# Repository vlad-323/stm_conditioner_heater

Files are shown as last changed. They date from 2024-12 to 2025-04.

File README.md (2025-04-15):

# stm_conditioner_heater
 Прилад дозволяє керувати компресором, обігрівом компресора та обігрівом піддона.
 # Схема електрична принципова
project
 # Зовнішній вигляд приладу

 # Логіка роботи
 1. Ініціалізація усіх входів та виходів
 2. Якщо вхід компресора вимкнений -> компресор і ТЕН компресора вимкнені
 3. work in progress...

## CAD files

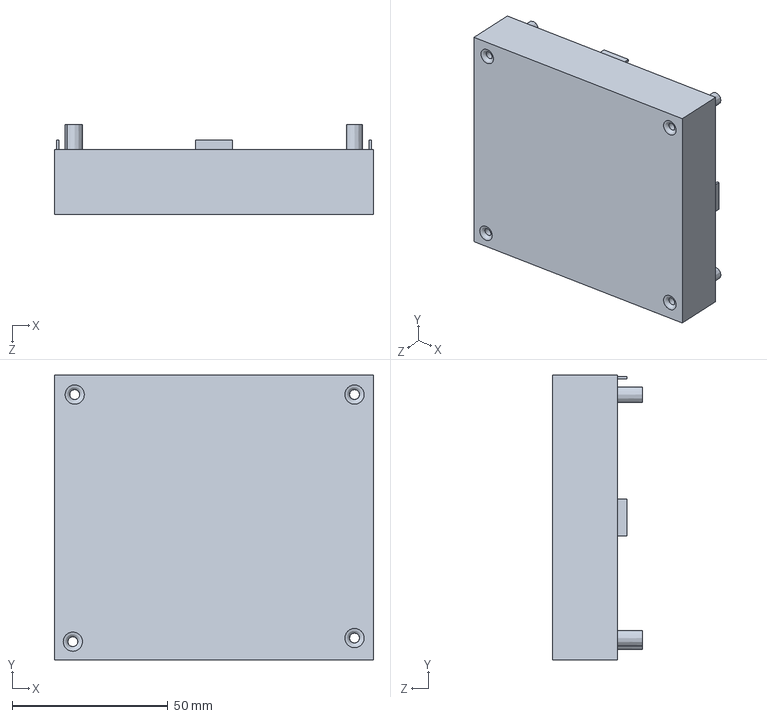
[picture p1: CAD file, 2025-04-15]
case/cond_control_TOP.SLDPRT
102.5 x 91.5 x 29.0 mm

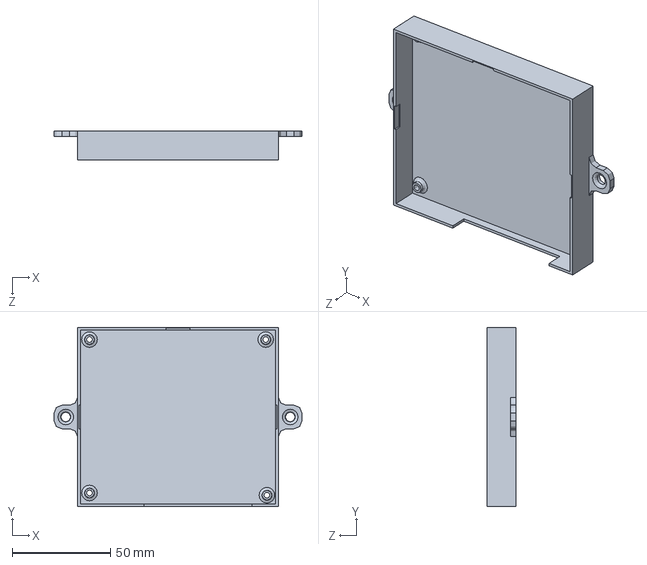
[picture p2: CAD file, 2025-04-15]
case/cond_control.SLDPRT
126.5 x 91.5 x 15.0 mm

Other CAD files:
case/cond_control.STL
case/cond_control_TOP.STL

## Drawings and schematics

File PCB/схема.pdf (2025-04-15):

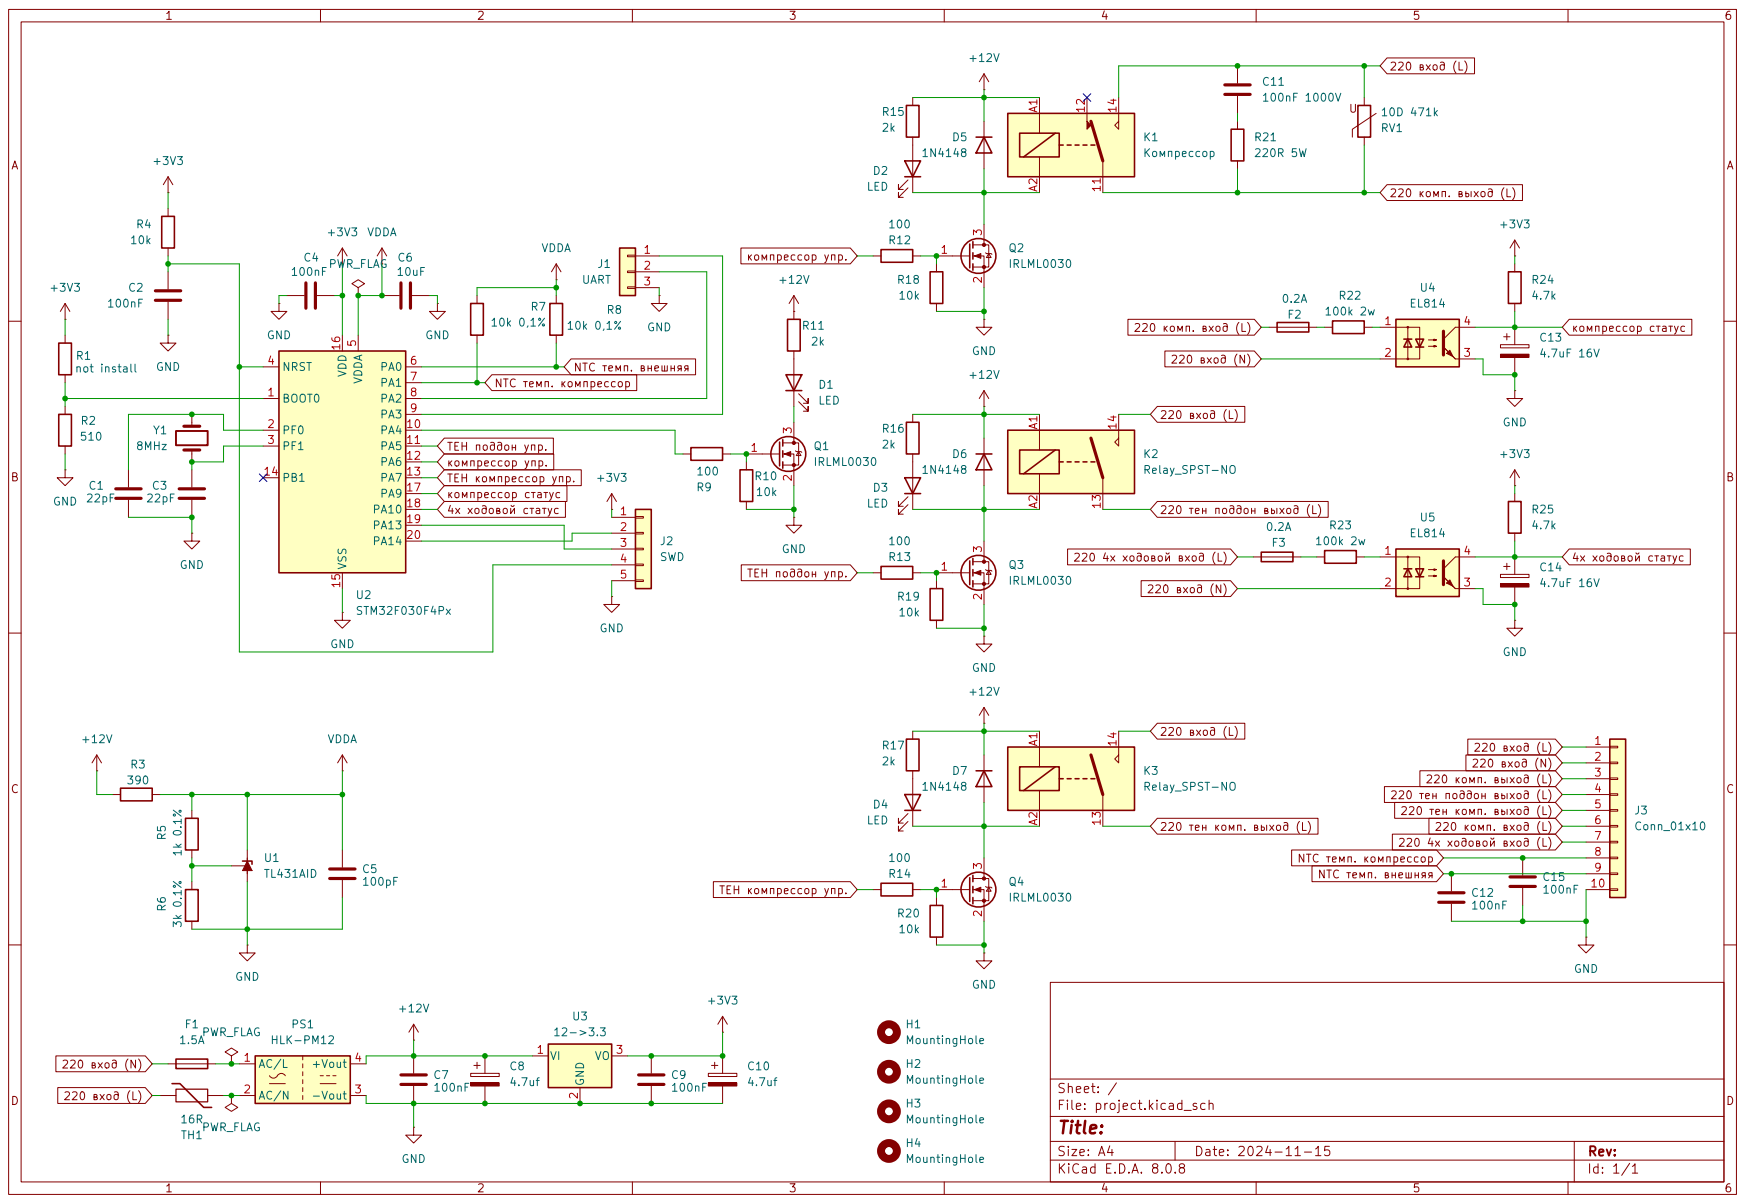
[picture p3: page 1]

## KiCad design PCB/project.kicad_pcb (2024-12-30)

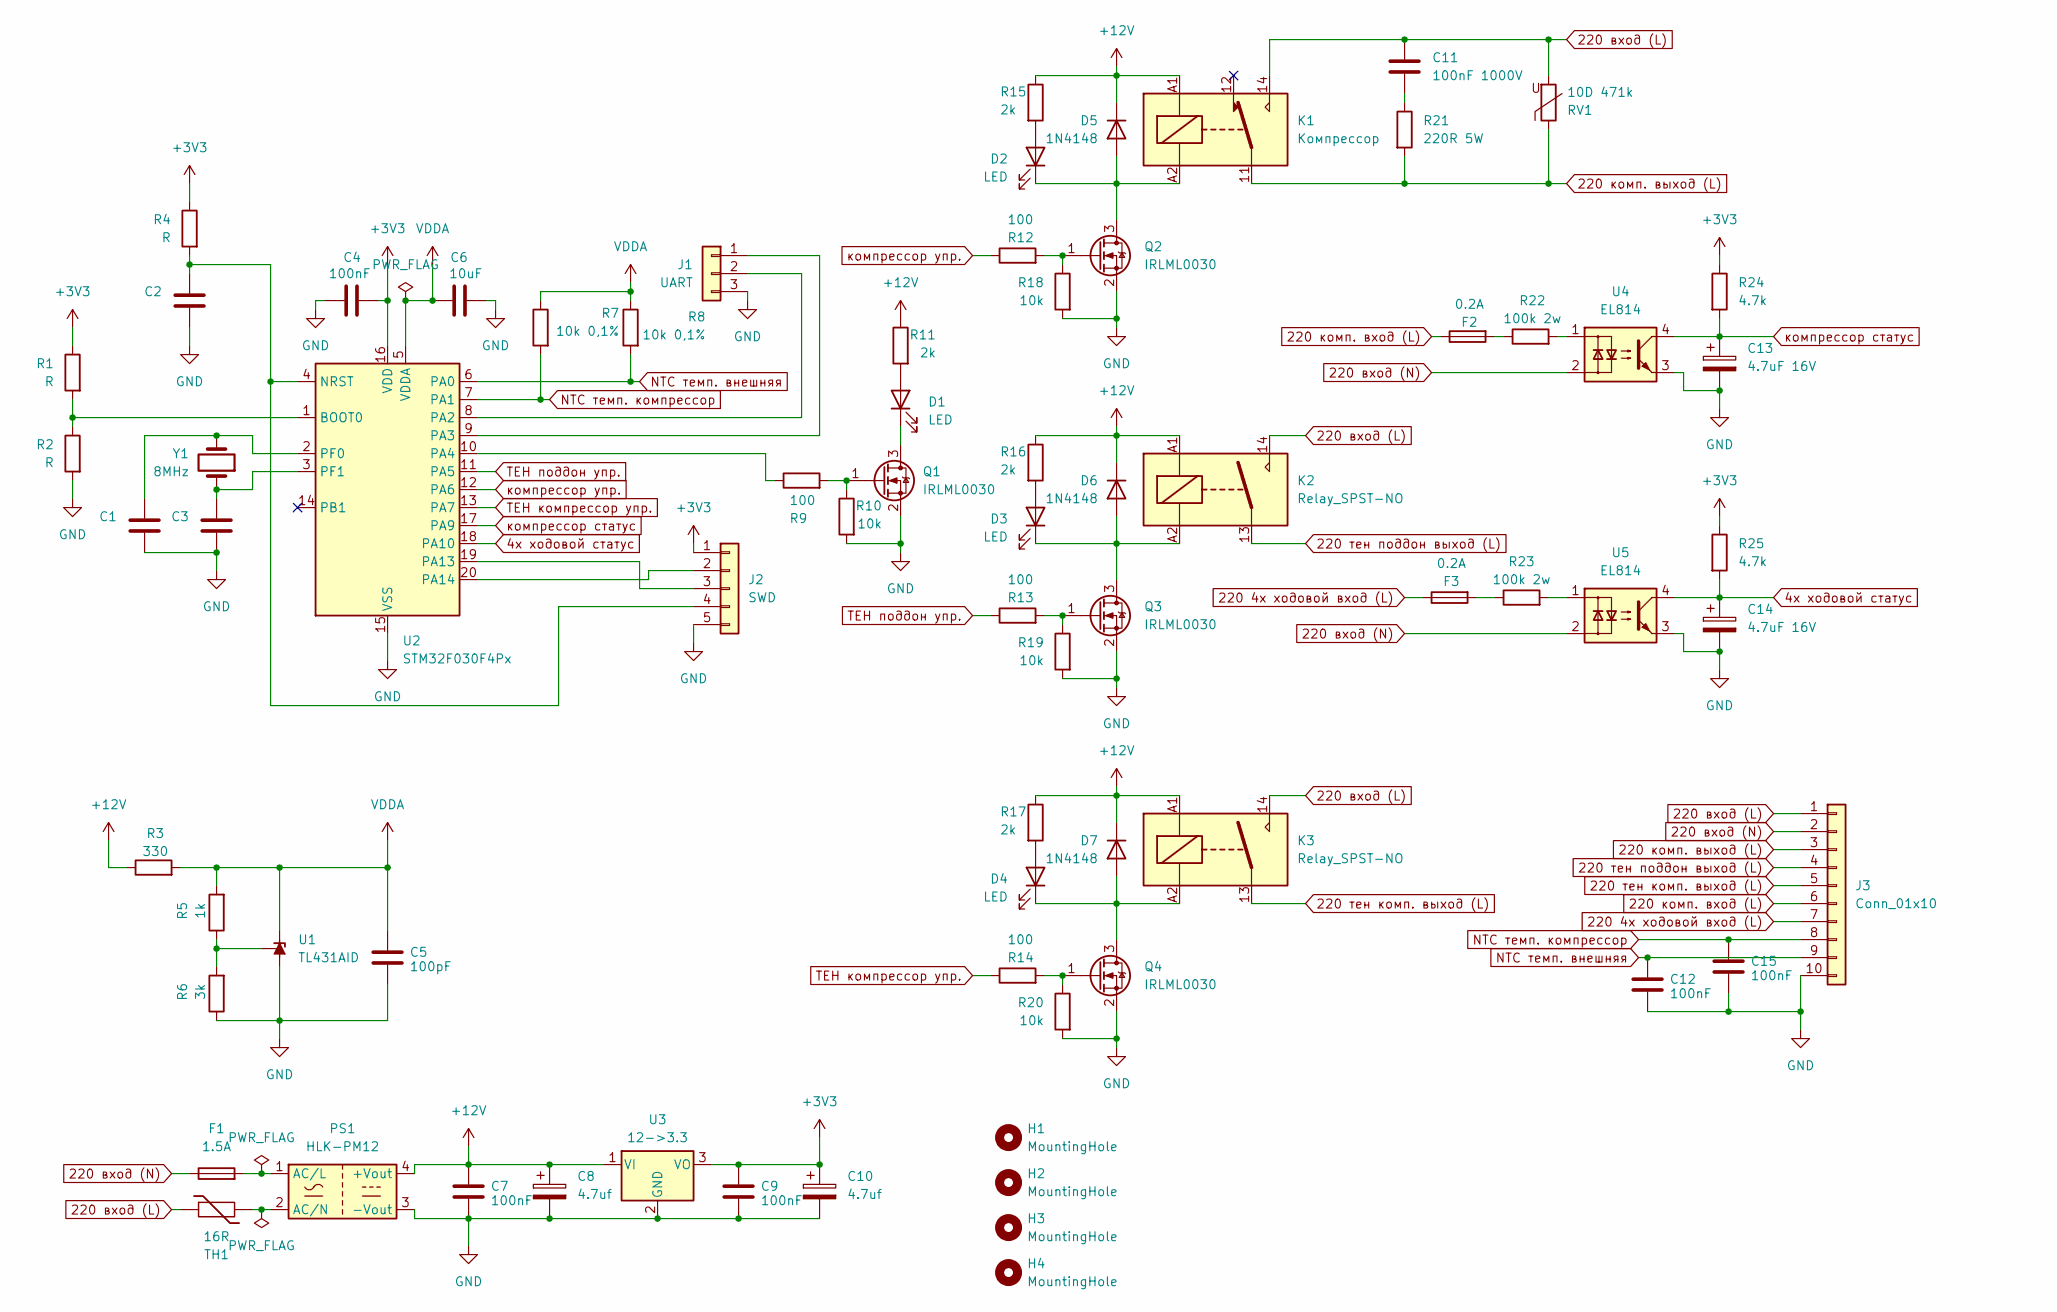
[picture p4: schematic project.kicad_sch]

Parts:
C1, C2, C3: C; C_0805_2012Metric_Pad1.18x1.45mm_HandSolder
C4, C7, C9, C12, C15: 100nF; C_0805_2012Metric_Pad1.18x1.45mm_HandSolder
C5: 100pF; C_0805_2012Metric_Pad1.18x1.45mm_HandSolder
C6: 10uF; C_0805_2012Metric_Pad1.18x1.45mm_HandSolder
C8, C10: 4.7uf; CP_Radial_D5.0mm_P2.50mm
C11: 100nF 1000V; C_Axial_L12.0mm_D6.5mm_P15.00mm_Horizontal
C13, C14: 4.7uF 16V; CP_Radial_D5.0mm_P2.00mm
D1, D2, D3, D4: LED; LED_D3.0mm
D5, D6, D7: 1N4148; D_DO-35_SOD27_P7.62mm_Horizontal
F1: 1.5A; Fuse_BelFuse_0ZRE0016FF_L9.9mm_W3.8mm
F2, F3: 0.2A; Fuse_BelFuse_0ZRE0016FF_L9.9mm_W3.8mm
H1, H2, H3, H4: MountingHole; MountingHole_3.2mm_M3
J1: UART; PinHeader_1x03_P2.54mm_Vertical
J2: SWD; PinHeader_1x05_P2.54mm_Vertical
J3: Conn_01x10; PhoenixContact_MSTB_2,5_10-GF-5,08_1x10_P5.08mm_Horizontal_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
K1: Компрессор; Relay_SPDT_RAYEX-L90S
K2, K3: Relay_SPST-NO; Relay_SPST_Schrack-RP-II-1-FormA_RM3.5mm
PS1: HLK-PM12; Converter_ACDC_Hi-Link_HLK-PMxx
Q1, Q2, Q3, Q4: IRLML0030; SOT-23W_Handsoldering
R1, R2, R4: R; R_0805_2012Metric_Pad1.20x1.40mm_HandSolder
R3: 330; R_1206_3216Metric_Pad1.30x1.75mm_HandSolder
R5: 1k; R_1206_3216Metric_Pad1.30x1.75mm_HandSolder
R6: 3k; R_1206_3216Metric_Pad1.30x1.75mm_HandSolder
R7, R8: 10k 0,1%; R_1206_3216Metric_Pad1.30x1.75mm_HandSolder
R9, R12, R13, R14: 100; R_0805_2012Metric_Pad1.20x1.40mm_HandSolder
R10, R18, R19, R20: 10k; R_0805_2012Metric_Pad1.20x1.40mm_HandSolder
R11, R15, R16, R17: 2k; R_0805_2012Metric_Pad1.20x1.40mm_HandSolder
R21: 220R 5W; R_Axial_DIN0918_L18.0mm_D9.0mm_P25.40mm_Horizontal
R22, R23: 100k 2w; R_Axial_DIN0207_L6.3mm_D2.5mm_P5.08mm_Vertical
R24, R25: 4.7k; R_0805_2012Metric_Pad1.20x1.40mm_HandSolder
RV1: 10D 471k; RV_Disc_D9mm_W3.4mm_P5mm
TH1: 16R; R_Axial_DIN0617_L17.0mm_D6.0mm_P7.62mm_Vertical
U1: TL431AID; SOT-23_Handsoldering
U2: STM32F030F4Px; TSSOP-20_4.4x6.5mm_P0.65mm
U3: 12->3.3; TO-220-3_Vertical
U4, U5: EL814; DIP-4_W7.62mm_LongPads
Y1: 8MHz; Crystal_HC18-U_Vertical

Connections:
4х ходовой статус: C14.1, R25.2, U2.18 (PA10), U5.4
220 4х ходовой вход (L): F3.1, J3.7
220 вход (L): C11.1, J3.1, K1.14, K2.14, K3.14, RV1.2, TH1.1
220 вход (N): F1.1, J3.2, U4.2, U5.2
220 комп. вход (L): F2.1, J3.6
220 комп. выход (L): J3.3, K1.11, R21.2, RV1.1
220 тен комп. выход (L): J3.5, K3.13
220 тен поддон выход (L): J3.4, K2.13
+3V3: C4.1, C9.1, C10.1, J2.1, R1.1, R4.1, R24.1, R25.1, U2.16 (VDD), U3.3 (VO)
+12V: C7.1, C8.1, D5.1 (K), D6.1 (K), D7.1 (K), K1.A1, K2.A1, K3.A1, PS1.4 (+Vout), R3.1, R11.1, R15.1, R16.1, R17.1, U3.1 (VI)
GND: C1.2, C2.2, C3.2, C4.2, C5.2, C6.2, C7.2, C8.2, C9.2, C10.2, C12.2, C13.2, C14.2, C15.2, J1.3, J2.5, J3.10, PS1.3 (-Vout), Q1.2 (S), Q2.2 (S), Q3.2 (S), Q4.2 (S), R2.2, R6.1, R10.2, R18.2, R19.2, R20.2, U1.3 (A), U2.15 (VSS), U3.2 (GND), U4.3, U5.3
NTC темп. внешняя: C12.1, J3.9, R8.2, U2.6 (PA0)
NTC темп. компрессор: C15.1, J3.8, R7.2, U2.7 (PA1)
unnamed: C11.2, R21.1
unnamed: D1.2 (A), R11.2
unnamed: D1.1 (K), Q1.3 (D)
unnamed: D2.2 (A), R15.2
unnamed: D2.1 (K), D5.2 (A), K1.A2, Q2.3 (D)
unnamed: D3.2 (A), R16.2
unnamed: D3.1 (K), D6.2 (A), K2.A2, Q3.3 (D)
unnamed: D4.2 (A), R17.2
unnamed: D4.1 (K), D7.2 (A), K3.A2, Q4.3 (D)
unnamed: F2.2, R22.1
unnamed: F3.2, R23.1
unnamed: J1.1, U2.9 (PA3)
unnamed: J1.2, U2.8 (PA2)
unnamed: J2.2, U2.20 (PA14)
unnamed: J2.3, U2.19 (PA13)
unnamed: C2.1, J2.4, R4.2, U2.4 (NRST)
unnamed: F1.2, PS1.1 (AC/L)
unnamed: PS1.2 (AC/N), TH1.2
unnamed: Q1.1 (G), R9.2, R10.1
unnamed: Q2.1 (G), R12.2, R18.1
unnamed: Q3.1 (G), R13.2, R19.1
unnamed: Q4.1 (G), R14.2, R20.1
unnamed: R22.2, U4.1
unnamed: R23.2, U5.1
unnamed: R5.1, R6.2, U1.2 (REF)
unnamed: R1.2, R2.1, U2.1 (BOOT0)
unnamed: R9.1, U2.10 (PA4)
unnamed: C1.1, U2.2 (PF0), Y1.2
unnamed: C3.1, U2.3 (PF1), Y1.1
VDDA: C5.1, C6.1, R3.2, R5.2, R7.1, R8.1, U1.1 (K), U2.5 (VDDA)
ТЕН компрессор упр.: R14.1, U2.13 (PA7)
ТЕН поддон упр.: R13.1, U2.11 (PA5)
компрессор статус: C13.1, R24.2, U2.17 (PA9), U4.4
компрессор упр.: R12.1, U2.12 (PA6)

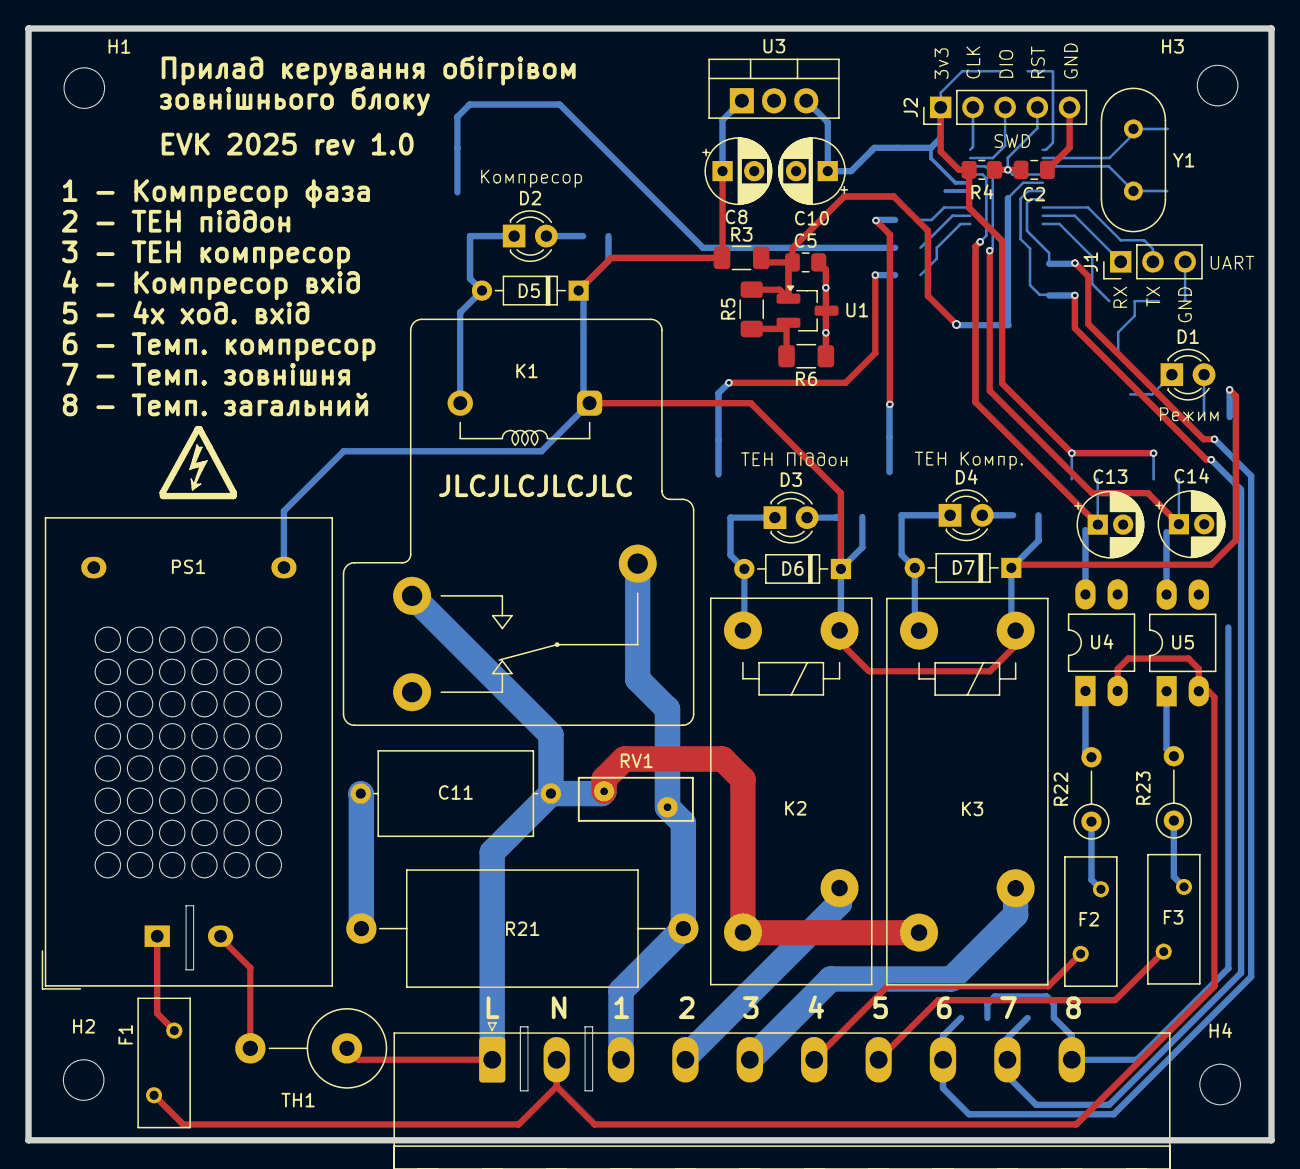
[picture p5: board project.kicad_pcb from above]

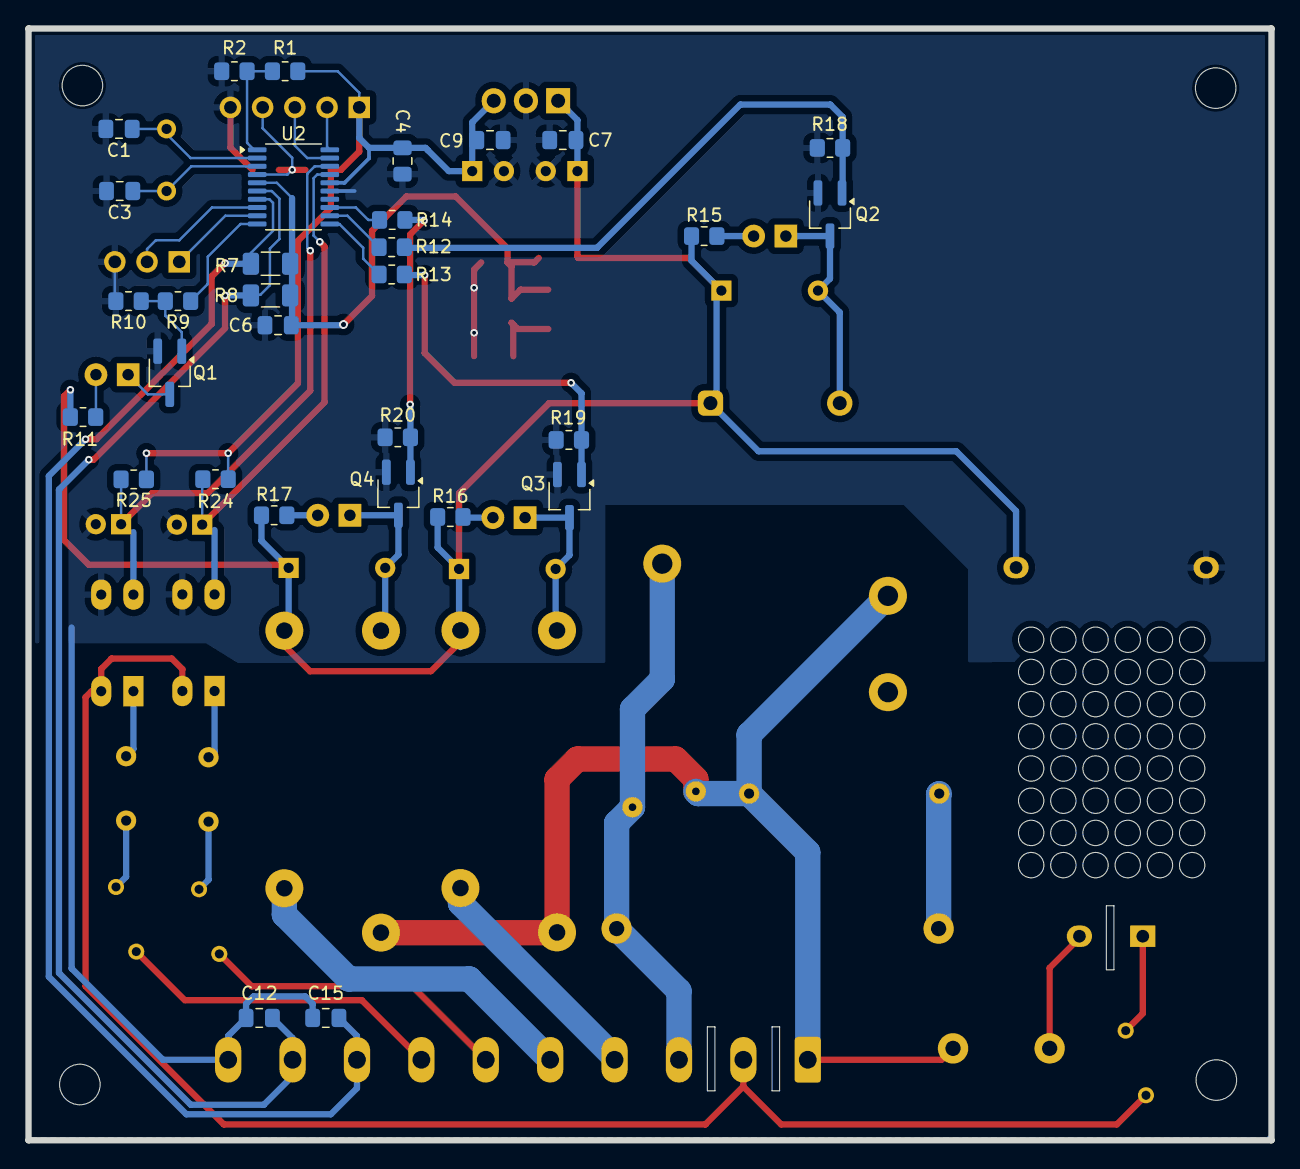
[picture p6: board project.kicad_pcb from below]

Board: 2 copper layers, 98.1 x 87.7 mm, 73 parts (31 on the bottom side), 47 nets.

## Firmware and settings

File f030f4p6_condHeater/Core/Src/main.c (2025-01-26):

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
/* Includes ------------------------------------------------------------------*/
#include "main.h"

/* USER CODE BEGIN Includes */
#include "stdlib.h"
#include "stdio.h"
/* USER CODE END Includes */


/* USER CODE BEGIN PV */
unsigned char buffer[50] = {'\0'};
/* Variables for ADC conversion data */
__IO uint16_t ADC_Data[3] = {0};

/* USER CODE END PV */

void SystemClock_Config(void);
static void MX_GPIO_Init(void);
static void MX_DMA_Init(void);
static void MX_ADC_Init(void);
static void MX_USART1_UART_Init(void);
/* USER CODE BEGIN PFP */
void USARTSend(unsigned char *pucBuffer, unsigned long ulCount);
/* USER CODE END PFP */

/* USER CODE BEGIN 0 */


void USARTSend(unsigned char *pucBuffer, unsigned long ulCount)
{
    //
    // Loop while there are more characters to send.
    //
    while(ulCount--)
    {
    	LL_USART_TransmitData8(USART1, *pucBuffer++);
        /* Loop until the end of transmission */
    	while(!LL_USART_IsActiveFlag_TXE(USART1));
    }
}


/* USER CODE END 0 */

/**
  * @brief  The application entry point.
  * @retval int
  */
int main(void)
{

  /* USER CODE BEGIN 1 */
  __IO uint32_t wait_loop_index = 0;
  /* USER CODE END 1 */

  /* MCU Configuration--------------------------------------------------------*/

  /* Reset of all peripherals, Initializes the Flash interface and the Systick. */
  LL_APB1_GRP2_EnableClock(LL_APB1_GRP2_PERIPH_SYSCFG);
  LL_APB1_GRP1_EnableClock(LL_APB1_GRP1_PERIPH_PWR);

  /* SysTick_IRQn interrupt configuration */
  NVIC_SetPriority(SysTick_IRQn, 3);

  /* Configure the system clock */
  SystemClock_Config();

  /* Initialize all configured peripherals */
  MX_GPIO_Init();
  MX_DMA_Init();
  MX_ADC_Init();
  MX_USART1_UART_Init();
  /* USER CODE BEGIN 2 */
  LL_DMA_ConfigAddresses(DMA1,
                         LL_DMA_CHANNEL_1,
                         LL_ADC_DMA_GetRegAddr(ADC1, LL_ADC_DMA_REG_REGULAR_DATA),
                         (uint32_t)&ADC_Data,
                         LL_DMA_DIRECTION_PERIPH_TO_MEMORY);
  LL_DMA_SetDataLength(DMA1, LL_DMA_CHANNEL_1, 2);
  LL_DMA_EnableIT_TC(DMA1, LL_DMA_CHANNEL_1);
  LL_DMA_EnableIT_TE(DMA1, LL_DMA_CHANNEL_1);
  LL_DMA_EnableChannel(DMA1, LL_DMA_CHANNEL_1);

  LL_ADC_StartCalibration(ADC1);
  while (LL_ADC_IsCalibrationOnGoing(ADC1) != 0) {}
  wait_loop_index = ((LL_ADC_DELAY_CALIB_ENABLE_ADC_CYCLES * 32) >> 1);
  while(wait_loop_index != 0)
  {
    wait_loop_index--;
  }
  LL_ADC_Enable(ADC1);
  LL_ADC_REG_StartConversion(ADC1);

  uint16_t value_in0, value_in1 = 0;
  /* USER CODE END 2 */

  /* Infinite loop */
  /* USER CODE BEGIN WHILE */
  while (1)
  {

	  value_in0 = ADC_Data[0]; // темп. коспрессора
	  value_in1 = ADC_Data[1]; // темп. внешняя

      sprintf(buffer, "Val 1:%d\r\n", value_in0 );
      USARTSend(buffer, sizeof(buffer));

      sprintf(buffer, "Val 2:%d\r\n", value_in1 );
      USARTSend(buffer, sizeof(buffer));

      // логика управления работой компрессора и тена компрессора
      if (LL_GPIO_IsInputPinSet(Compr_state_GPIO_Port, Compr_state_Pin)) // если на входе компрессора - ничего (выс. уровень) -> компр. и тен компр. выключены
      {
    	  LL_GPIO_ResetOutputPin(Compr_ctrl_GPIO_Port, Compr_ctrl_Pin);
    	  LL_GPIO_ResetOutputPin(TEN_compr_ctrl_GPIO_Port, TEN_compr_ctrl_Pin);
      }

      if (!LL_GPIO_IsInputPinSet(Compr_state_GPIO_Port, Compr_state_Pin)) // если на входе компрессора - 220 (низкий уровень)...
      {
    	  if (value_in0 > 2000) // проверяем температуру, если меньше 0 С (ПРОВЕРИТЬ !!!)
    	  {
    		  LL_GPIO_SetOutputPin(TEN_compr_ctrl_GPIO_Port, TEN_compr_ctrl_Pin); // включаем тен, греем компрессор
    		  LL_GPIO_ResetOutputPin(Compr_ctrl_GPIO_Port, Compr_ctrl_Pin);
    	  }
    	  else // компрессор теплый, греть не имеет смысла
    	  {
    		  LL_GPIO_ResetOutputPin(TEN_compr_ctrl_GPIO_Port, TEN_compr_ctrl_Pin); // выключаем тен
    		  LL_GPIO_SetOutputPin(Compr_ctrl_GPIO_Port, Compr_ctrl_Pin); // а компрессор включаем
    	  }
      }

      // логика работы для режима оттайки
      if (LL_GPIO_IsOutputPinSet(Compr_ctrl_GPIO_Port, Compr_ctrl_Pin) && LL_GPIO_IsInputPinSet(Valve_state_GPIO_Port, Valve_state_Pin) && value_in1 > 2000) // включен компрессор, 4х ходовой отключен и температура на улице меньше 0
      {
    	  LL_GPIO_SetOutputPin(TEN_pallet_ctrl_GPIO_Port,TEN_pallet_ctrl_Pin);
      }
      else
      {
    	  LL_GPIO_ResetOutputPin(TEN_pallet_ctrl_GPIO_Port,TEN_pallet_ctrl_Pin);
      }


      //LL_mDelay(500);
    /* USER CODE END WHILE */

    /* USER CODE BEGIN 3 */
  }
  /* USER CODE END 3 */
}

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


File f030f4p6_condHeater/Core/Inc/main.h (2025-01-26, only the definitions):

#define NTC_outside_Pin LL_GPIO_PIN_0
#define NTC_outside_GPIO_Port GPIOA
#define NTC_compr_Pin LL_GPIO_PIN_1
#define NTC_compr_GPIO_Port GPIOA
#define LED_state_Pin LL_GPIO_PIN_4
#define LED_state_GPIO_Port GPIOA
#define TEN_pallet_ctrl_Pin LL_GPIO_PIN_5
#define TEN_pallet_ctrl_GPIO_Port GPIOA
#define Compr_ctrl_Pin LL_GPIO_PIN_6
#define Compr_ctrl_GPIO_Port GPIOA
#define TEN_compr_ctrl_Pin LL_GPIO_PIN_7
#define TEN_compr_ctrl_GPIO_Port GPIOA
#define Compr_state_Pin LL_GPIO_PIN_9
#define Compr_state_GPIO_Port GPIOA
#define Valve_state_Pin LL_GPIO_PIN_10
#define Valve_state_GPIO_Port GPIOA
#define NVIC_PRIORITYGROUP_0         ((uint32_t)0x00000007) /*!< 0 bit  for pre-emption priority,
#define NVIC_PRIORITYGROUP_1         ((uint32_t)0x00000006) /*!< 1 bit  for pre-emption priority,
#define NVIC_PRIORITYGROUP_2         ((uint32_t)0x00000005) /*!< 2 bits for pre-emption priority,
#define NVIC_PRIORITYGROUP_3         ((uint32_t)0x00000004) /*!< 3 bits for pre-emption priority,
#define NVIC_PRIORITYGROUP_4         ((uint32_t)0x00000003) /*!< 4 bits for pre-emption priority,

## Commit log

2024-11-16 Updated schematic(not finished)
    [project.kicad_sch]
2024-11-17 Updated PCB (still not finished)
    [project.kicad_pcb, project.kicad_sch]
2024-12-30 PCB and schematic done
    [project-B_Cu.gbr, project-B_Mask.gbr, project-B_Paste.gbr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]
2025-01-26 Updated PCB
    [project.kicad_sch]
2025-04-15 Added case
    [cond_control.SLDPRT, cond_control.STL, cond_control_TOP.SLDPRT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]
2025-04-15 added schematic

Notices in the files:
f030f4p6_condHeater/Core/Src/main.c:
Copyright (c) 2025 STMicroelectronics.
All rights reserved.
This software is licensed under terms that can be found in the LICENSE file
